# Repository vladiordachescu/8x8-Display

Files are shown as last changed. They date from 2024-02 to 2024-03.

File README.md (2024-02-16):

# 8x8 Display with Attiny85 microcontroller
proteus sch

8x8display



https://github.com/vladiordachescu/8x8-display-attiny85/assets/73362552/db192aa6-c74f-46c0-92d8-602dc996fab3

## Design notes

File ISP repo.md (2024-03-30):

Check out my ISP repo at https://github.com/vladiordachescu/attiny25-45-85-isp-shield for building an ISP shield to upload the code on the ATtiny25/45/85 microcontroller. 🙈

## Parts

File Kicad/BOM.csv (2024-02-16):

# | Reference | Qty | Value | Footprint | DNP
1 | A1, B1 | 2 | SN74LS164DR | SN74LS164DR:SOIC127P600X175-14N
2 | D1, D2, D3, D4, D5, D6, D7, D8, D9, D10, D11, D12, D13, D14, D15, D16, D17, D18, D19, D20, D21, D22, D23, D24, D25, D26, D27, D28, D29, D30, D31, D32, D33, D34, D35, D36, D37, D38, D39, D40, D41, D42, D43, D44, D45, D46, D47, D48, D49, D50, D51, D52, D53, D54, D55, D56, D57, D58, D59, D60, D61, D62, D63, D64 | 64 | LED | LED_SMD:LED_0805_2012Metric
3 | J1 | 1 | Barrel_Jack_Switch | Connector_BarrelJack:BarrelJack_Horizontal
4 | R1, R2, R3, R4, R5, R6, R7, R8 | 8 | 220 | Resistor_SMD:R_0805_2012Metric
5 | SW1 | 1 | SW_Push_DPDT | Push_6pin:push_cu_6_pini
6 | U1, U2 | 2 | 74LS08 | SN74LS164DR:SOIC127P600X175-14N
7 | U3 | 1 | ATtiny85-20P | Package_DIP:DIP-8_W7.62mm

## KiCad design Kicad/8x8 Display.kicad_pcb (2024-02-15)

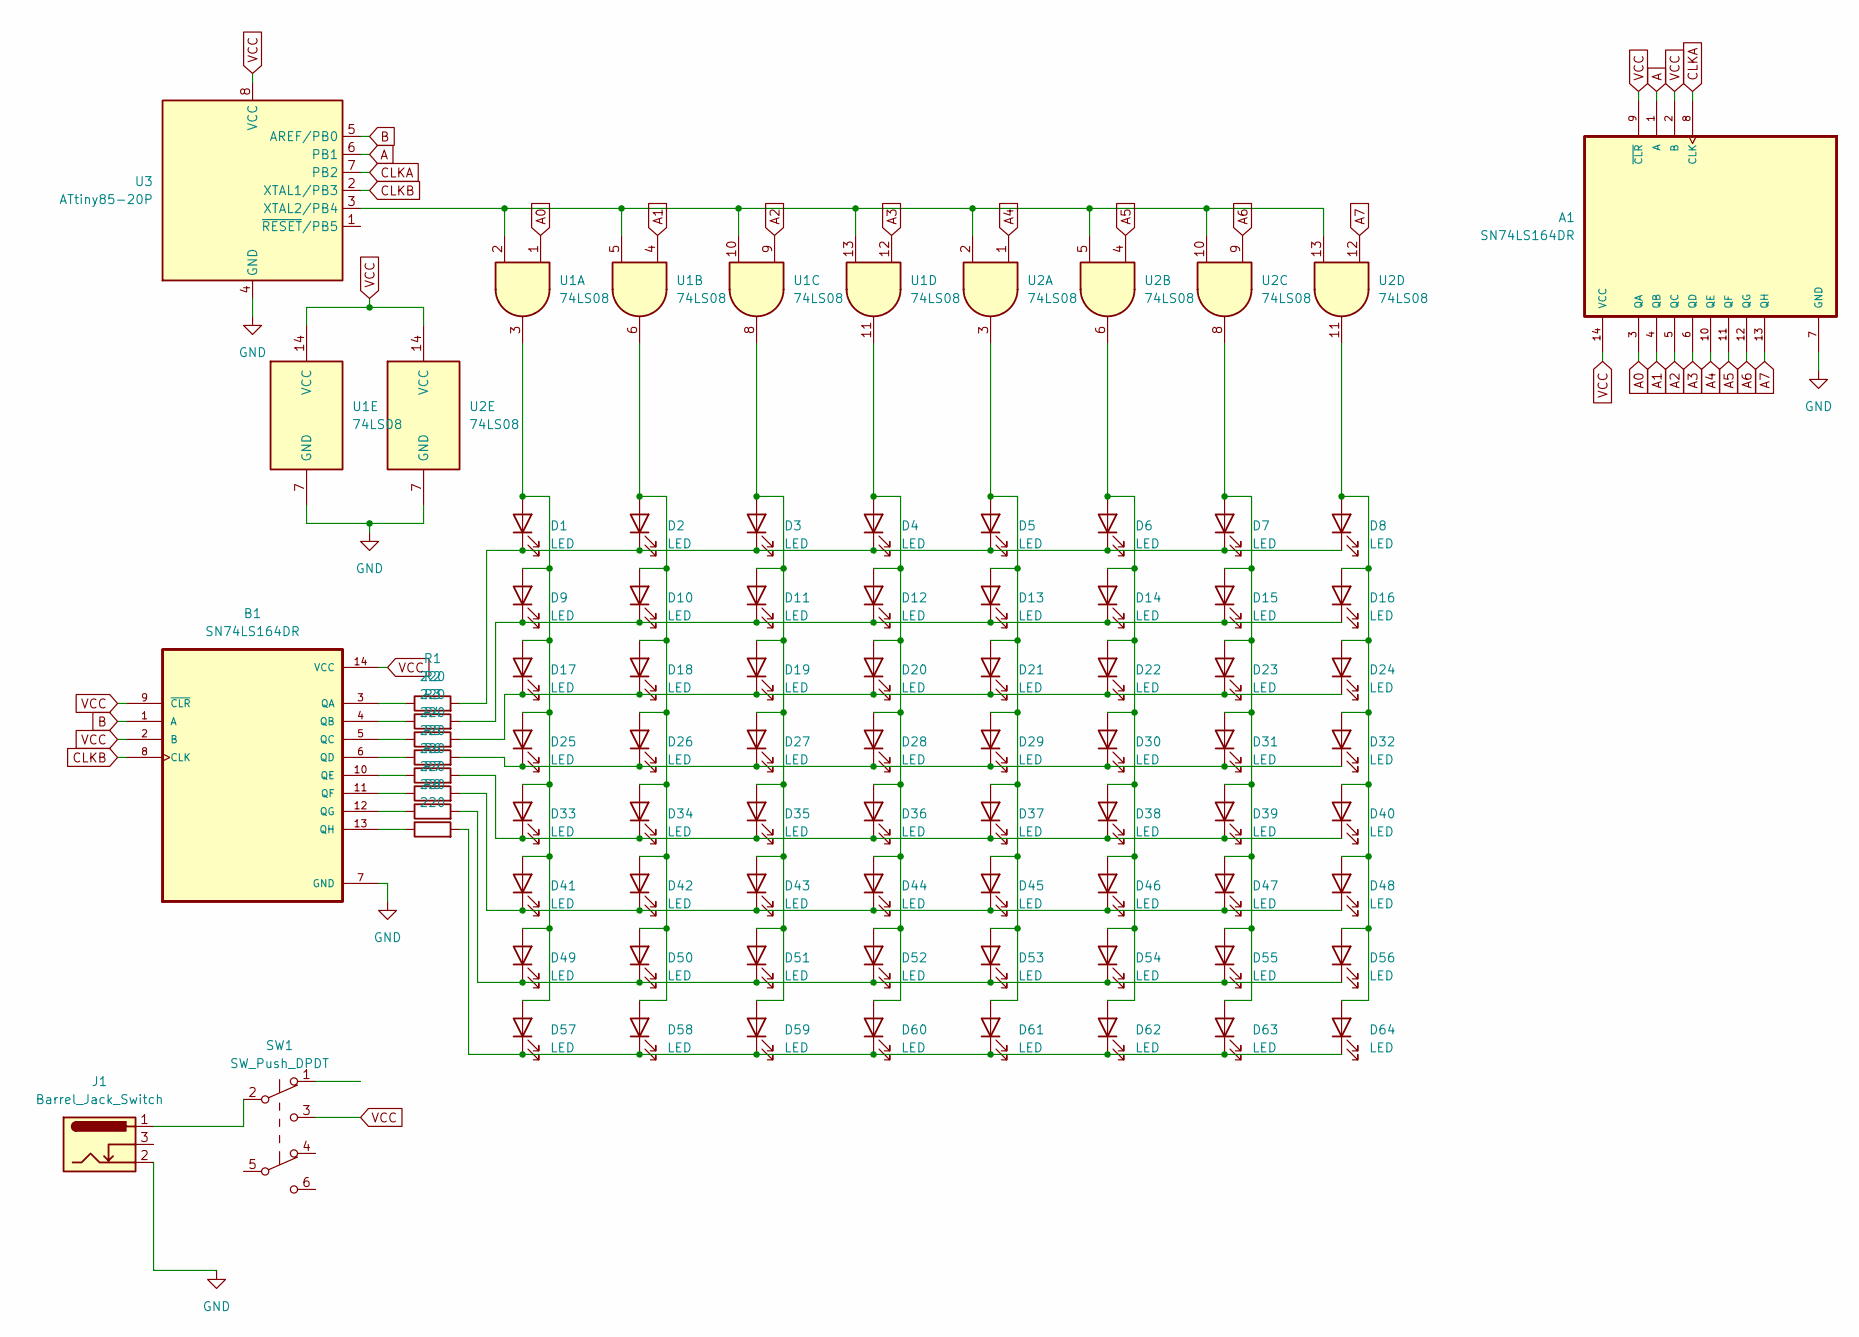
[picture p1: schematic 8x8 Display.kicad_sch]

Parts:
A1: SN74LS164DR; SOIC127P600X175-14N
B1: SN74LS164DR; SOIC127P600X175-14N
D1, D2, D3, D4, D5, D6, D7, D8, D9, D10, D11, D12, D13, D14, D15, D16, D17, D18, D19, D20, D21, D22, D23, D24, D25, D26, D27, D28, D29, D30, D31, D32, D33, D34, D35, D36, D37, D38, D39, D40, D41, D42, D43, D44, D45, D46, D47, D48, D49, D50, D51, D52, D53, D54, D55, D56, D57, D58, D59, D60, D61, D62, D63, D64: LED; LED_0805_2012Metric
J1: Barrel_Jack_Switch; BarrelJack_Horizontal
R1, R2, R3, R4, R5, R6, R7, R8: 220; R_0805_2012Metric
SW1: SW_Push_DPDT; push_cu_6_pini
U1: 74LS08; SOIC127P600X175-14N
U2: 74LS08
U3: ATtiny85-20P; DIP-8_W7.62mm

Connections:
A: A1.1 (A), U3.6 (PB1)
A0: A1.3 (QA), U1.1
A1: A1.4 (QB), U1.4
A2: A1.5 (QC), U1.9
A3: A1.6 (QD), U1.12
A4: A1.10 (QE), U2.1
A5: A1.11 (QF), U2.4
A6: A1.12 (QG), U2.9
A7: A1.13 (QH), U2.12
B: B1.1 (A), U3.5 (AREF/PB0)
CLKA: A1.8 (CLK), U3.7 (PB2)
CLKB: B1.8 (CLK), U3.2 (XTAL1/PB3)
GND: A1.7 (GND), B1.7 (GND), J1.2, U1.7 (GND), U2.7 (GND), U3.4 (GND)
unnamed: B1.3 (QA), R1.1
unnamed: B1.4 (QB), R2.1
unnamed: B1.5 (QC), R3.1
unnamed: B1.6 (QD), R4.1
unnamed: B1.10 (QE), R5.1
unnamed: B1.11 (QF), R6.1
unnamed: B1.12 (QG), R7.1
unnamed: B1.13 (QH), R8.1
unnamed: D1.2 (A), D9.2 (A), D17.2 (A), D25.2 (A), D33.2 (A), D41.2 (A), D49.2 (A), D57.2 (A), U1.3
unnamed: D1.1 (K), D2.1 (K), D3.1 (K), D4.1 (K), D5.1 (K), D6.1 (K), D7.1 (K), D8.1 (K), R1.2
unnamed: D2.2 (A), D10.2 (A), D18.2 (A), D26.2 (A), D34.2 (A), D42.2 (A), D50.2 (A), D58.2 (A), U1.6
unnamed: D9.1 (K), D10.1 (K), D11.1 (K), D12.1 (K), D13.1 (K), D14.1 (K), D15.1 (K), D16.1 (K), R2.2
unnamed: D3.2 (A), D11.2 (A), D19.2 (A), D27.2 (A), D35.2 (A), D43.2 (A), D51.2 (A), D59.2 (A), U1.8
unnamed: D4.2 (A), D12.2 (A), D20.2 (A), D28.2 (A), D36.2 (A), D44.2 (A), D52.2 (A), D60.2 (A), U1.11
unnamed: D5.2 (A), D13.2 (A), D21.2 (A), D29.2 (A), D37.2 (A), D45.2 (A), D53.2 (A), D61.2 (A), U2.3
unnamed: D6.2 (A), D14.2 (A), D22.2 (A), D30.2 (A), D38.2 (A), D46.2 (A), D54.2 (A), D62.2 (A), U2.6
unnamed: D7.2 (A), D15.2 (A), D23.2 (A), D31.2 (A), D39.2 (A), D47.2 (A), D55.2 (A), D63.2 (A), U2.8
unnamed: D8.2 (A), D16.2 (A), D24.2 (A), D32.2 (A), D40.2 (A), D48.2 (A), D56.2 (A), D64.2 (A), U2.11
unnamed: D17.1 (K), D18.1 (K), D19.1 (K), D20.1 (K), D21.1 (K), D22.1 (K), D23.1 (K), D24.1 (K), R3.2
unnamed: D25.1 (K), D26.1 (K), D27.1 (K), D28.1 (K), D29.1 (K), D30.1 (K), D31.1 (K), D32.1 (K), R4.2
unnamed: D33.1 (K), D34.1 (K), D35.1 (K), D36.1 (K), D37.1 (K), D38.1 (K), D39.1 (K), D40.1 (K), R5.2
unnamed: D41.1 (K), D42.1 (K), D43.1 (K), D44.1 (K), D45.1 (K), D46.1 (K), D47.1 (K), D48.1 (K), R6.2
unnamed: D49.1 (K), D50.1 (K), D51.1 (K), D52.1 (K), D53.1 (K), D54.1 (K), D55.1 (K), D56.1 (K), R7.2
unnamed: D57.1 (K), D58.1 (K), D59.1 (K), D60.1 (K), D61.1 (K), D62.1 (K), D63.1 (K), D64.1 (K), R8.2
unnamed: J1.1, SW1.2 (B)
unnamed: U1.2, U1.5, U1.10, U1.13, U2.2, U2.5, U2.10, U2.13, U3.3 (XTAL2/PB4)
VCC: A1.2 (B), A1.9 (~CLR), A1.14 (VCC), B1.2 (B), B1.9 (~CLR), B1.14 (VCC), SW1.3 (C), U1.14 (VCC), U2.14 (VCC), U3.8 (VCC)

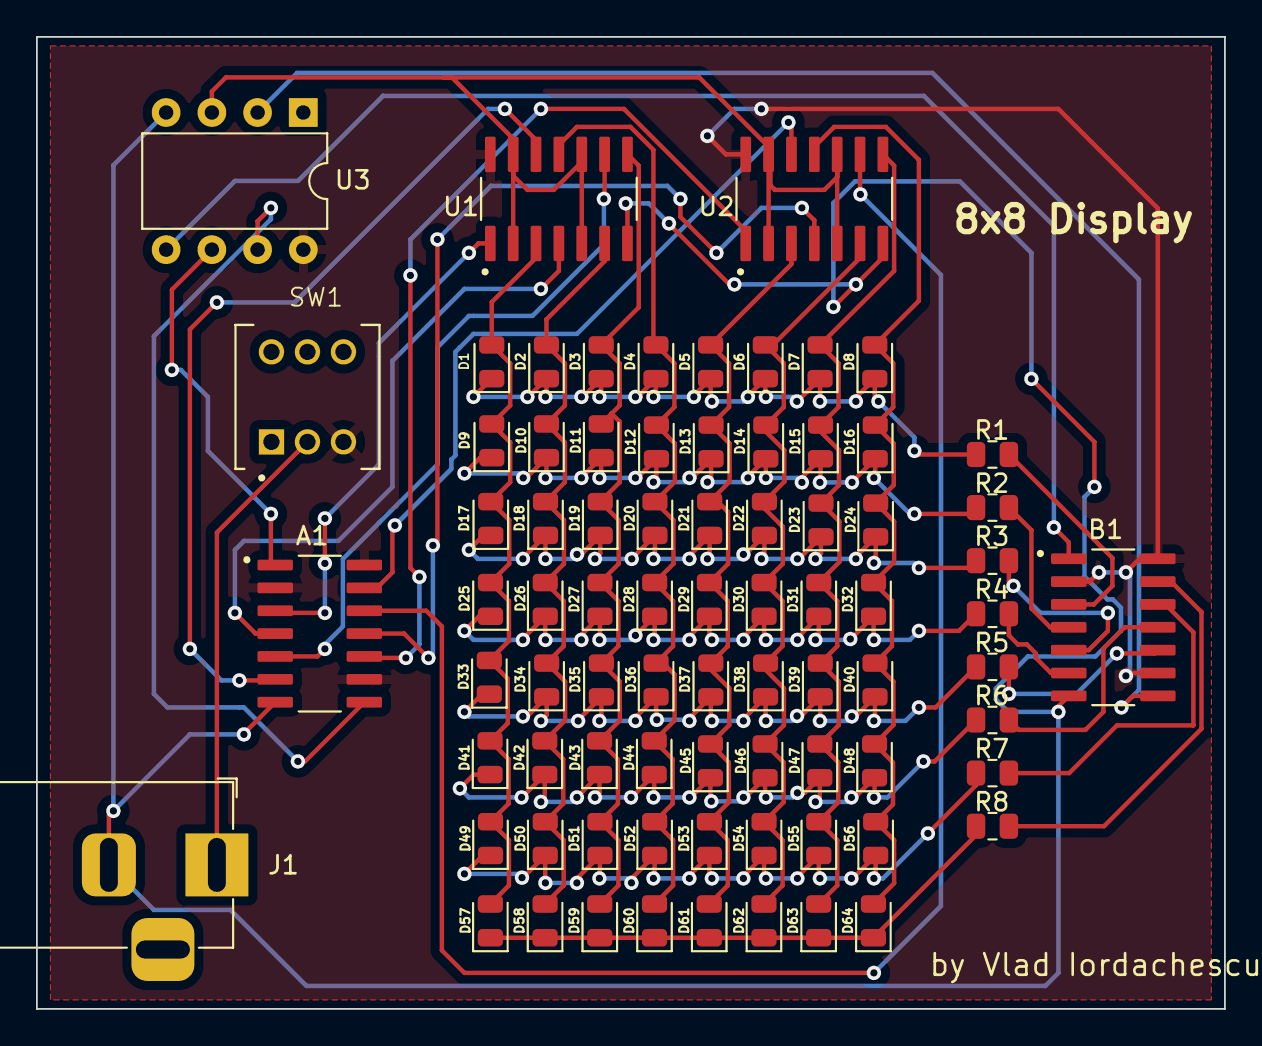
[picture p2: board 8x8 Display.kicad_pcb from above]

Board: 2 copper layers, 66.0 x 54.0 mm, 79 parts (0 on the bottom side), 40 nets.

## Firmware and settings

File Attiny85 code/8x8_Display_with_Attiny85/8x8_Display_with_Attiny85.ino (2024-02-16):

/*
  > CLKA is used to generate a clock signal for the A shift register which sweeps through the LED columns (LED anodes).
  > CLKB is used to generate a clock signal for the B shift register which sweeps through the LED rows (LED cathodes). It's 8 times slower than CLKA.
  > A is used to generate a single pulse at every 8th period of CLKA, which will propagate through the A shift register's 8 outputs.
  > B (actively low) is used to generate a single pulse at every 8th period of CLKB (64th period of CLKA), which will propagate through the B shift register's 8 outputs.
  > EN is associated with the draw[64] byte array. It has a LOW state if an element from the array has a value of 0 and a HIGH state otherwise.
  > The reset pin of the microcontroller is not connected (NC).
*/



const int CLKA = 2;
const int CLKB = 3;
const int A = 1;
const int B = 0;
const int EN = 4;


unsigned int CLK_cnt = 0;
bool highCLKB = true;

byte draw[64] = {
  0, 0, 0, 0, 0, 0, 0, 0,
  0, 0, 1, 1, 1, 1, 1, 0,
  0, 1, 1, 1, 1, 0, 1, 0,
  0, 1, 0, 1, 1, 0, 1, 0,
  0, 1, 0, 0, 1, 0, 1, 0,
  0, 1, 1, 1, 1, 1, 1, 0,
  0, 0, 0, 0, 0, 1, 0, 0,
  0, 0, 0, 0, 0, 1, 0, 0
};

void setup() {
  pinMode(CLKA, OUTPUT);
  pinMode(CLKB, OUTPUT);
  pinMode(A, OUTPUT);
  pinMode(B, OUTPUT);
  pinMode(EN, OUTPUT);

/*
  B is set to HIGH and we generate 8 CLKB periods in order to set B shift register's outputs to HIGH before we start displaying the array.
  This ensures that when we start the main loop, during the first 8 periods of CLKB, only one LED row consisting of cathodes at a time will be LOW.
*/

  digitalWrite(B, HIGH);

  for (int i = 0; i < 8; i++) {
    // delay is purely optional, it helps to visualize the setup process during the simulation.
    digitalWrite(CLKB, HIGH);
    delay(10);
    digitalWrite(CLKB, LOW);
    delay(10);
  }
}

void loop() {

  if (draw[CLK_cnt])
    digitalWrite(EN, HIGH);
  else
    digitalWrite(EN, LOW);

  if (!(CLK_cnt % 8))
    digitalWrite(A, HIGH);

  if (!CLK_cnt)
    digitalWrite(B, LOW);

  if (!(CLK_cnt % 4)) { //generates semiperiods for CLKB

    if (highCLKB) {
      digitalWrite(CLKB, HIGH);
      highCLKB = false;
    }

    else {
      digitalWrite(CLKB, LOW);
      highCLKB = true;
    }
  }

  /*
     Each of A shift registers' 8 outputs will stay HIGH for 20ms sequencially.
     This results in a refresh rate of 1/(64*20ms) = 0.78125 Hz for the display, which depending
     on the simulation's speed, could be enough for seeing each LED light up individually.
  */

  // For a 30Hz display refresh rate, replace the delays with the commented code.
  digitalWrite(CLKA, HIGH);
  delay(10); //delayMicroseconds(260);
  digitalWrite(CLKA, LOW);
  digitalWrite(A, LOW);
  digitalWrite(B, HIGH);
  delay(10); //delayMicroseconds(260);

  CLK_cnt = (CLK_cnt + 1) % 64;
}

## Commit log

2024-02-15 Added schematic and pcb files
    [8x8 Display.kicad_pcb, 8x8 Display.kicad_sch]
2024-02-15 Added BOM
    [BOM.csv]
2024-02-15 Formatting BOM.csv
    [BOM.csv]
